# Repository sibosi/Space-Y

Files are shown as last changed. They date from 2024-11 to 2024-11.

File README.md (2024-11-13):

# Space-Y

## Linkek
- [Ütemterv](https://github.com/users/sibosi/projects/5)
- [Szuperfájl](https://docs.google.com/document/d/1ejDll2n5JYhOkpturbacC6KUA010AB2t2pER_i0fCP8/edit?tab=t.0)
- [PDR template](https://docs.google.com/document/d/1FQSjlzJh2AtvqQ_X5NmcszUTd-Xnn7Zh/edit#heading=h.gjdgxs)
- [Space Y - PDR](https://docs.google.com/document/d/141c5Cl6St4Da276F4Kb5j9x9D-nOoFfTdNVciU082j8/edit?tab=t.0#heading=h.3dy6vkm)
- [Versenyszabályzat](https://www.cansatverseny.hu/szabalyzat)

## A csapattagok
- [Balázs László](https://github.com/balaslaszlomarton)
- [Simon Nimród](https://github.com/sibosi)
- [Kalmár Benedek](https://github.com/Kollegue1)
- [Horváh Maja](https://github.com/bonobo15)
- [Katona Salamon](https://github.com/GuestUser1324243)

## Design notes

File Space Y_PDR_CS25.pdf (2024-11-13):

# Space Y Előzetes tervfelülvizsgálat

2024. november 13.

# Tartalomjegyzék (kötelező)

1. A csapat bemutatása | 3
2. Ütemterv | 3
3. A küldetések áttekintése | 3
4. Kockázatok, várható nehézségek | 3
5. Mechanikai - szerkezeti tervezés | 3
6. Elektromos tervezés | 4
6.1 Általános felépítés | 4
6.2 A másodlagos küldetés eszközei | 4
6.3 Energiaellátás | 4
6.4 Kommunikációs rendszer | 4
7. Szoftver | 4
8. Visszatérési rendszer | 5
9. Földi állomás (ground station) | 5
10. Ismeretterjesztés, kommunikáció (outreach) | 5

# 1. A csapat bemutatása

Mi az V. kerületi Eötvös József Gimnázium diákjai vagyunk a 10.D. 10.C és 9. E osztályokból. Mentorunk Holicsné Csejk Gabriella, aki segít nekünk ha a projekt megvalósításával kapcsolatban van kérdésünk.

Balás László Márton - csapatvezető
Csapat munkájának vezetője. A projekt fizikai megvalósíthatóságáért felel.

Simon Nimród - szoftverszakértő
Feladata a CanSat programozása, a szenzorokból az információ kinyerése és mentése a fedélzetre.

Benedek Kalmár - hardverszakértő
Saját Arduino-s projektjeivel jártas a szenzorok és áramkörök világában. A projektben a feladata az hardveres elektronika kivitelezése.

Horváth Maja - mérnök
Feladata a papírforma gyakorlatba ültetése.

Katona Salamon - 3D modellező
Feladata a CanSat szerkezetének megtervezése 3D-ben.

# 2. Ütemterv

Feladat | Kezdet | Vég | 2024 2025
11/ 11 | 11/ 21 | 12/ 1 | 12/ 11 | 12/ 21 | 12/ 31 | 1/ 10 | 1/ 20 | 1/ 30 | 2/ 9 | 2/ 19 | 3/ 1 | 3/ 11 | 3/ 21 | 3/ 31
Teljes verseny | 2024-11-13 | 2025-04-01
1. Szakasz | 2024-11-13 | 2025-01-13
2. Szakasz | 2025-01-03 | 2025-02-20
3. Szakasz | 2025-02-9 | 2025-04-01

GANTT Táblázat
Az ütemtervünk 3 szakaszra tagolódik:
Az 1. szakaszban megépítjük és külön külön teszteljük a fő elemek prototípusait. A végére azt akarjuk elérni, hogy össze tudjuk rakni az első teljes CanSat prototípust.
A 2. szakaszban a teljes CanSat prototípusokat akarjuk tesztelni és fejleszteni. Ennek a szakasznak az a célja, hogy a végére minden elem működjön együtt a CanSat-ben és hogy már egy akár kilövésre kész verziónk legyen. A CDR ekkora már majdnem kész lesz.
A 3. szakasz a végső simítások és optimalizálások alkalma. A szakasz fő célja a PLR és magára a kilövésre a felkészülés.

# 3. A küldetések áttekintése

1. Elsődleges küldetése
a. A légnyomást és a hőmérsékletet is a kezdőszettből kapott légnyomás és hőmérővel fogjuk mérni.
2. A másodlagos küldetések, amiket a CanSat-en elvégzünk két dolgot szeretnének mérni:
a. Azt, hogy a sebesség tényleg állandó lesz az ejtőernyő kinyitása után és hogy ez a sebesség ténylegesen megfelel az elvártaknak( 8. Visszatérési rendszer). Ezt egy accelero méterrel mérnénk. Ezzel bizonyítanak
mg = | összefüggést. A CanSat helyzetét is szeretnénk

1
2 × ρ × C
d

× A × v

2

rögziteni a GPS-en, hogy meg tudjuk találni landolás után és hogy útját is vissza lehessen majd nézni.
b. Azt is meg szeretnénk figyelni, hogy az űrben valóban nem terjed a hang. Ehhez hogy egy mikrofont és egy hangszórót is bele építünk a cansatbe. Miért is kell hangszóró, azért kell, hogy biztosan legyen egy hangforrás.
c. A küldetés változtatás jogát fent szeretnénk tartani, elsősorban egy biológiai kísérlet számára.

# 4. Kockázatok, várható nehézségek

E projekt megvalósításához számos ismerettel rendelkezünk, (mint a programozás, a 3D tervezés vagy a nyomtatás,) viszont a megvalósításhoz néhány akadállyal meg kell a küzdenünk:

Probléma | Megoldás
Szerteágazó feladatok Még nem foglalkoztunk ilyen szinten interdiszciplináris projekttel. | A szervezés nagy része a GitHub (https://github.com/sibosi/Space-Y?tab=readme-ov-file) segítségével történik. Itt… ● A kódunkat egységesen tudjuk tárolni, ● Ha bármelyikünk elveszne, a ReadMe segít eligazodni, ● A GitHub projektünkön (https://github.com/users/sibosi/projects/5) belül mindig nyomonkövethetjük a feladatokat és határidőket, ● A projekten belül egyénre leosztva látjuk, ki hogyan halad a feladataival, így látjuk, ha valamelyikünk segítségre szorul.
Rádiókommunikáció korábban egyikünk sem foglalkozott rádiókommunikációval. | Tanulás terén rugalmasak vagyunk, így bármilyen ismeretlen terület csínját-bínját szívesen elsajátítjuk. (Illetve könnyen kérünk segítséget ismeretségi körből.)

Vázanyag
Korábban már használtunk 3D nyomtatót, viszont számunkra kérdéses az anyag strapabírása. Attól tartunk, hogy a váz érkezéskor sérülhet.

A váz képességeit tesztelésnek vetjük alá, hogy szükség esetén ezeket korrigálhassuk.

Váratlan problémák
Nem vagyunk jósok, így könnyen elképzelhetőnek tartjuk, hogy éles helyzetben váratlan problémákkal kell szembenéznünk.

A versenyhelyzetet tesztelések során minél pontosabban szeretnénk szimulálni a kellemetlenségek elkerülése érdekében.

# 5. Mechanikai - szerkezeti felépítés

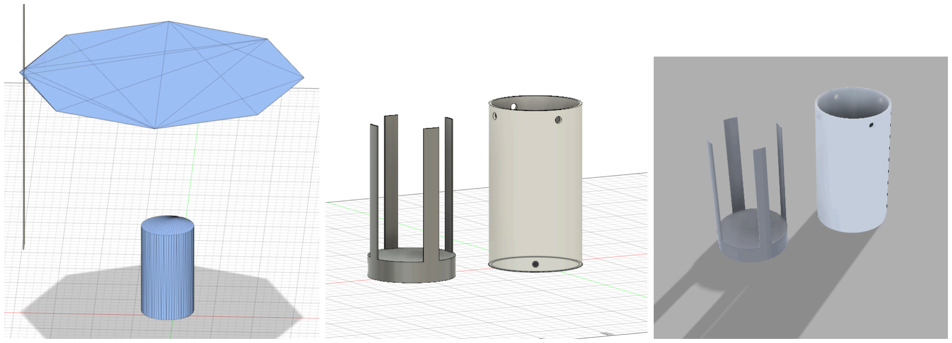
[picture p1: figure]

A cansatünk felépítésének a vázlatos modellje a képeken láthatóak. A modellek pontosak, de még közel sem véglegesek!

Ami látható a jelenlegi terveken:
1. A jobb oldali szürke elem a cansat megvédéséért felelős. Ehhez kapcsolódik az ejtőernyő is.
2. A bal oldali fekete elem a jobb oldali elembe illeszkedik bele és ez tartalmazza az elektronikát és a műszereket-> a terepen pillanatok alatt hozzá lehet férni az egyes alkatrészekhez, ha cserélni kéne valamit.
Ami még fejlesztés alatt van:
A. A rádiónak valo nyílás a bal oldali elemen
B. A két elemet egymásba záró szerkezet
C. Az elektronikának az elhelyezkedése a cansatben valamint az ezek rögzítésére szolgáló elemek.

# 6. Elektronikai felépítés

## 6.1 Általános felépítés

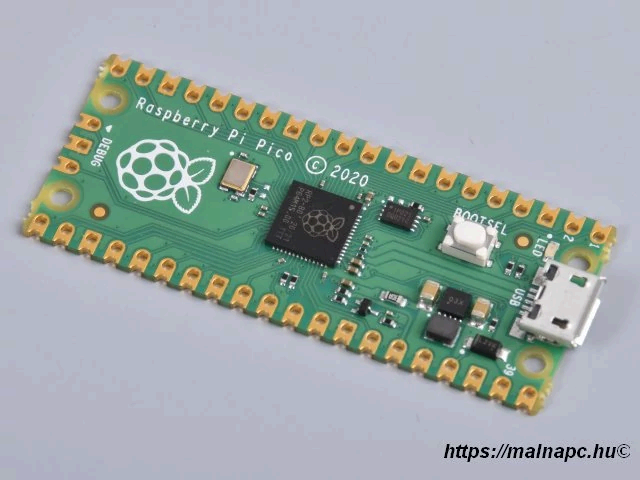
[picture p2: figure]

Raspberry Pi Pico (https://www.raspberrypi.com/documentation/microcontrollers/pico-series.html)
A CanSat agyát egy Raspberry Pi Pico számítógép képezi. Az elsődleges küldetés végrehajtásához szükséges méréseket egy BMP280 Hő- és légnyomásmérő (https://malnapc.hu/a2651-bmp280-i2c-spi-barometric-pressure-altitude-sensor?keyword=bmp280) fogja végezni. Az Ublox NEO-6M – GPS (https://www.microcontroller.hu/termek/ublox-neo-6m-gps-vevo-modul/) modul lesz a helymeghatározó rendszerünk fő eleme. A másodlagos küldetésekhez egy accelerometer-t fogunk használni és egy mikrofon (https://malnapc.hu/a1063-electret-microphone-amplifier) plusz passive buzzer (https://www.vigvari.hu/grove---passive-buzzer_673796) kombót. A rádiókommunikációhoz egy-egy AiThinker Ra-01 – LoRa adó-vevő modul-t (https://www.microcontroller.hu/termek/aithinker-ra-01-lora-ado-vevo-modul-antennaval/) a földön és a fedélzeten is. A CanSat által rögzített adatok az USB porton keresztül csatlakoztatott pendrive-on lesznek tárolva.

## 6.2 A másodlagos küldetés

A másodlagos küldetés során a sebességet egy gyorsulásmérővel (https://malnapc.hu/a2809-lis3dh-triple-axis-accelerometer-2g4g8g16g) és hang terjedését egy mikrofon (https://malnapc.hu/a1063-electret-microphone-amplifier) segítségével tervezzük vizsgálni. A CanSat-be egy GPS vevő modult (https://www.microcontroller.hu/termek/ublox-neo-6m-gps-vevo-modul/) is beépítünk, hogy folyamatosan nyomon követhessük földrajzi helyzetét a landolásig.

Landolás során azt vizsgáljuk, hogy a 8. Visszatérési rendszerben helyesek-e a számításaink, mely szerint a CanSat közel 9,003 m/s-os állandó sebességgel fog földet érni.

Annak érdekében, hogy biztosak lehessünk abban, hogy van hang, egy passive buzzer (https://www.vigvari.hu/grove---passive-buzzer_673796) használatával egyszerű hangot tervezünk lejátszani. Mivel a CanSat csak 1 km magasságba lesz fellőve, eredményként azt várjuk, hogy a mikrofon a passive buzzer hangkimenetét veszi fel.

## 6.3 Energiaellátás

Az alábbiakban bemutatjuk a CanSat energiafogyasztásával kapcsolatos becsléseinket. 50mAℎ + 90mAℎ + 30mAℎ + 45mAℎ + 1mAℎ + 1mAℎ = 220mAℎ Ahhoz hogy a CanSatünknek legalább 4-óráig legyen energia ellátása kell nekünk egy legalább 880 mAh-s akkumulátor.
220mAℎ × 4 = 880mAℎ
1200mA-s Li-Ion elemekkel akarjuk fedezni a CanSet fedélzeti energia szükségleteit. 1200mAh-val akár több mint 5 óraig tudnánk bekapcsolva tartani a CanSat-et.

1200mAℎ
220mAℎ = 5, 45ℎ

## 6.4 Kommunikációs rendszer

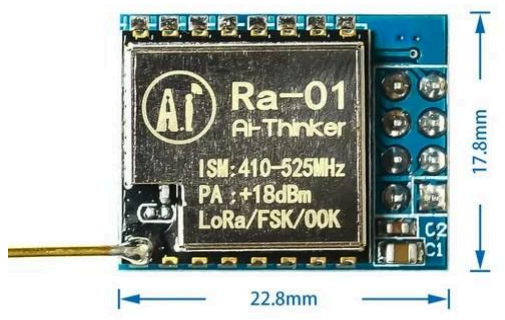
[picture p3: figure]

AiThinker Ra-01 – LoRa adó-vevő modul (https://www.microcontroller.hu/termek/aithinker-ra-01-lora-ado-vevo-modul-antennaval/)

A CanSat és a földi állomás között egyirányú kapcsolatot szeretnénk létrehozni, vagyis nem fogunk a földről adatokat küldeni. AiThinker Ra-01 – LoRa adó-vevő modult (https://www.microcontroller.hu/termek/aithinker-ra-01-lora-ado-vevo-modul-antennaval/) használnánk, amelynek előre csatlakoztatott antennája van. Mi azért választottuk a LoRa modult, mert nagy távolságban képes információtovábbításra. Terveink szerint a mért légnyomási és hőmérsékleti adatok, illetve a GPS modul által mért adatok kerülnek továbbításra a 433 MHz-es frekvencián.

# 7. Szoftver

A CanSat-unkat MicroPython nyelven tervezzük programozni. A kód a belső flash memórián kerül raktározásra, a gyűjtött adatokat pedig egy külső egységen tároljuk, melyet az USB porton csatlakoztatunk a Raspberry-hez.
A fejlesztői környezet változó, ugyanis a kódunkat GitHub segítségével közösen tudjuk szerkeszteni. Csapatunk elsősorban Visual Studio Code-ot használ.

# 8. Visszatérési rendszer

A képlet amivel dolgoztunk:

mg =

1
2 × C
d

× ρ × A × v

2

Jel: | Mit jelent: | Értéke:
m | Cansat tömege | 0,350kg
Cd | ernyő légellenállási együtthatója | 0,75
vmax | maximális sebesség | 11 m/s
vmin | minimális sebesség | 8 m/s
ρ | légsűrűség | 1,255 kg/m³
g | gravitációs gyorsulás | 9,81 m/s 2

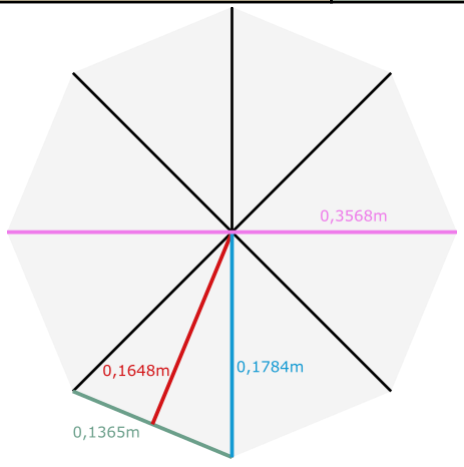
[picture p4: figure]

az ejtőernyő méretei

Ezekből az adatokból meg tudjuk állapítani az ejtőernyőnek a felületét a minimális és maximális sebesség értékre nézve: A =

2mg
C
d

ρv

2
Vmax esetén Amax

, Vmin esetén Amin

lesz a felület, az előző egyenlettel kiszámolva:
míg | . A mi CanSetünkön az ejtőernyő A=0,09m² A | -es max
≈ 0, 0603 m

2 A
min

≈ 0, 1140 m

2

lesz.

Ezzel a felülettel a sebesség: v = , a képletet felhasználva v=9,003 m/s

2mg
C
d

ρA

Ezzel a sebességgel 1000m-ről 111mp alatt fog földre érni, ha nem tekintjük az elején a gyorsulási szakaszt.
Az ernyő egy nyolcszög alakú lapos ernyő lesz.
Az ejtőernyőt a vázhoz kapcsoló kötél hossza és annak kiszámítása az alábbi linken található. (https://docs.google.com/spreadsheets/d/138BjXl9WQWX3PZVeIef-rV6MbGxG3MskhMv_7PDKWAg/edit?gid=0#gid=0)

# 9. Földi állomás (ground station)

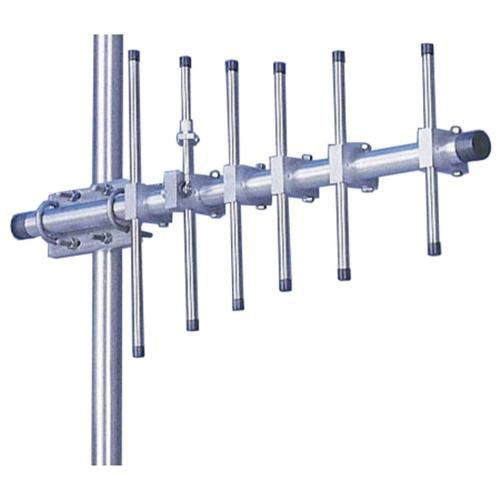
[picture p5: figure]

Yagi-Uda antenna

A földi állomáson ugyanazt a LoRa-t használnánk, mint amit a 6.4 Kommunikációs rendszerben. Az állomás úgy fog kinézni, hogy a LoRa-t összekötjük egy Raspberry Pi 3 Model (https://malnapc.hu/raspberry-pi-3-model-b-plus) B+ számítógéppel, amely az információkat továbbítja a központi laptophoz. A jeleket egy Uda Yagi típusú antennával szeretnénk befogadni.

# 10. Ismeretterjesztés, kommunikáció (outreach)

A munkafolyamatok közben GitHub-on (https://github.com/sibosi/Space-Y) és Youtube-on (https://www.youtube.com/channel/UCeXS5uswOhLeckqtKG_TUFQ) fogjuk dokumentálni a projekt menetét, a különféle teszteket és felmerülő akadályokat, azok átlépését és egyéb fontos részleteket. A projekt befejeztével a kapott adatokat és eredményeket elemeznénk, majd mindenki számára online hozzáférhetővé tennénk, ha olyan versenyre megyünk, ahol ezen eredmények hasznát vehetjük, használni fogjuk őket.

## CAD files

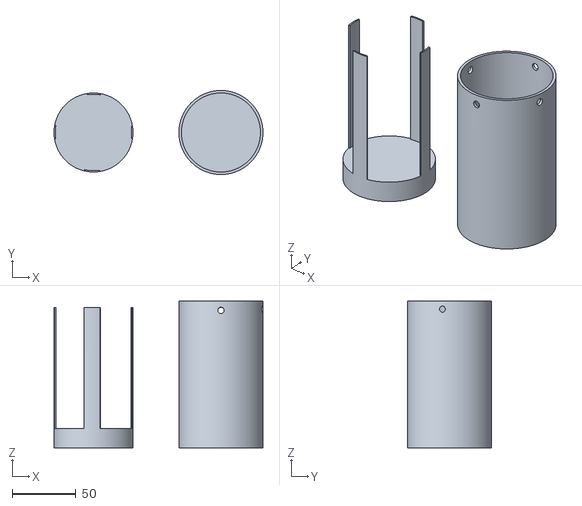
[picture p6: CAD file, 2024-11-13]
models/stl/beta v2_ (1).stl
164.0 x 66.0 x 115.0

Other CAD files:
models/fusion 360/beta v2_.f3z
